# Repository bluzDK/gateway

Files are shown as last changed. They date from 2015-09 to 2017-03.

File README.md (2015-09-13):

<p align="center" >
Bluz
</p>

Bluz Gateway Hardware Files
==========
Bluz is a Development Kit (DK) that implements the Wiring language and talks to the [Particle](https://www.particle.io/) cloud through Bluetooth Low Energy. It can be accessed through a REST API and programmed from a Web IDE.

These files have been made available online through a [Creative Commons Attribution-ShareAlike 3.0](http://creativecommons.org/licenses/by-sa/3.0/) license.

You are welcome to distribute, remix, and use these files for commercial purposes. If you do so, please attribute the original design to Bluz both on the website and on the physical packaging of the product or in the instruction manual. All derivative works must be published under the same or a similar license.

All items are subject to change over time as the product is designed, so make sure you are always looking at the latest information by pulling often.

##Sections
<b>BOM</b>: Current Bill of Materials for the gateway.

<b>Datasheets</b>: Datasheets for all major parts on the board.

<b>HW Design</b>: Schematics, board layouts, and other design files.

<b>3D Files</b>: 3D Models of the PCBA and Case

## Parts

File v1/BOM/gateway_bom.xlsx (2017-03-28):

Part(s) | Package | Value | Description | Qty | Manufacturer | Mfg. Part Number | Data Sheet | Notes
U2 | SMD |  | nrf51822 module with 32K RAM | 1 | Raytac | MDBT40 | data (http://www.raytac.com/download/MDBT40/MDBT40%20spec-Version%20M.pdf)
U1 | SOT-23 |  | Linear Regulator with 3.3V output | 1 | Microchip | MCP1825S-3302E/DB | data (http://www.microchip.com/mymicrochip/filehandler.aspx?ddocname=en531698)
U3 | SMD |  | Particle P1 Module | 1 | Particle | P1 | data (https://docs.particle.io/datasheets/p1-datasheet/)
U4 | SOIC-8 |  | 2Mb SPI Flash | 1 | Microchip | SST25VF020B-80-4I-SAE | data (http://ww1.microchip.com/downloads/en/DeviceDoc/20005054C.pdf)
Q1 |  | 32.768KHz | 20ppm, 9pF, 32.768KHz crystal | 1 |  | ABS06-32.768KHZ-9-T | data (http://www.abracon.com/Resonators/ABS06.pdf)
C1-C4, C8, C10, C12, C14 | 0603 | 0.1uF | 0603 Package | 8 |  | GRM188R71C104KA01D | data (http://search.murata.co.jp/Ceramy/image/img/A01X/partnumbering_e_01.pdf)
C5, C6 | 0603 | 12pF | 0603 Package | 2 |  | CL10C120JB8NNNC | data (http://www.samsungsem.com/kr/front/downloadcms.do?fileName=S_CL10C120JB8NNNC.pdf)
C7 | 0603 | 1uF | 0603 Package | 1 |  | CL10B105KP8NNNC | data (http://www.samsungsem.com/kr/front/downloadcms.do?fileName=S_CL10B105KP8NNNC.pdf)
C9, C11, C13, C15 | 0603 | 10uF | 0603 Package | 4 |  | CL10A106MQ8NNNC | data (http://www.samsungsem.com/kr/support/product-search/mlcc/__icsFiles/afieldfile/2015/08/14/S_CL10A106MQ8NNNL.pdf)
R1-R4 | 0603 | 1K Ohm | 1k Ohm | 4 |  | CRCW06031K00FKEA | data (http://www.vishay.com/docs/20035/dcrcwe3.pdf)
L1 | SMD |  | 3.2mm x 2.7m RGB LED | 1 |  | 597-7701-207F | data (http://www.dialight.com/Assets/Brochures_And_Catalogs/Indication/597-77x1-2xx.pdf)
J1 | Thru |  | USB A Male Connector | 1 | Molex | 480371000 | data (http://www.molex.com/pdm_docs/sd/480371000_sd.pdf)

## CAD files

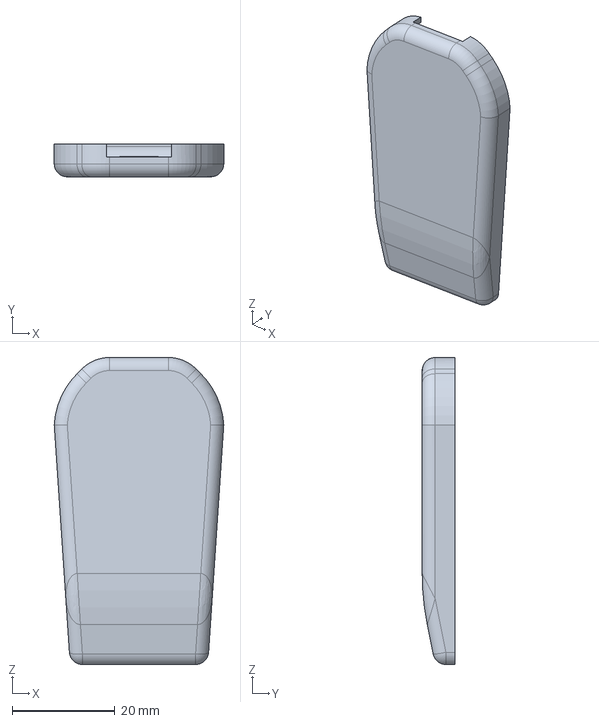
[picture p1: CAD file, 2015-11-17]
v1/3DFiles/Case/21mnb23.stp
33.0 x 6.35 x 59.7 mm

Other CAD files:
v1/3DFiles/Case/21mnb23.stl

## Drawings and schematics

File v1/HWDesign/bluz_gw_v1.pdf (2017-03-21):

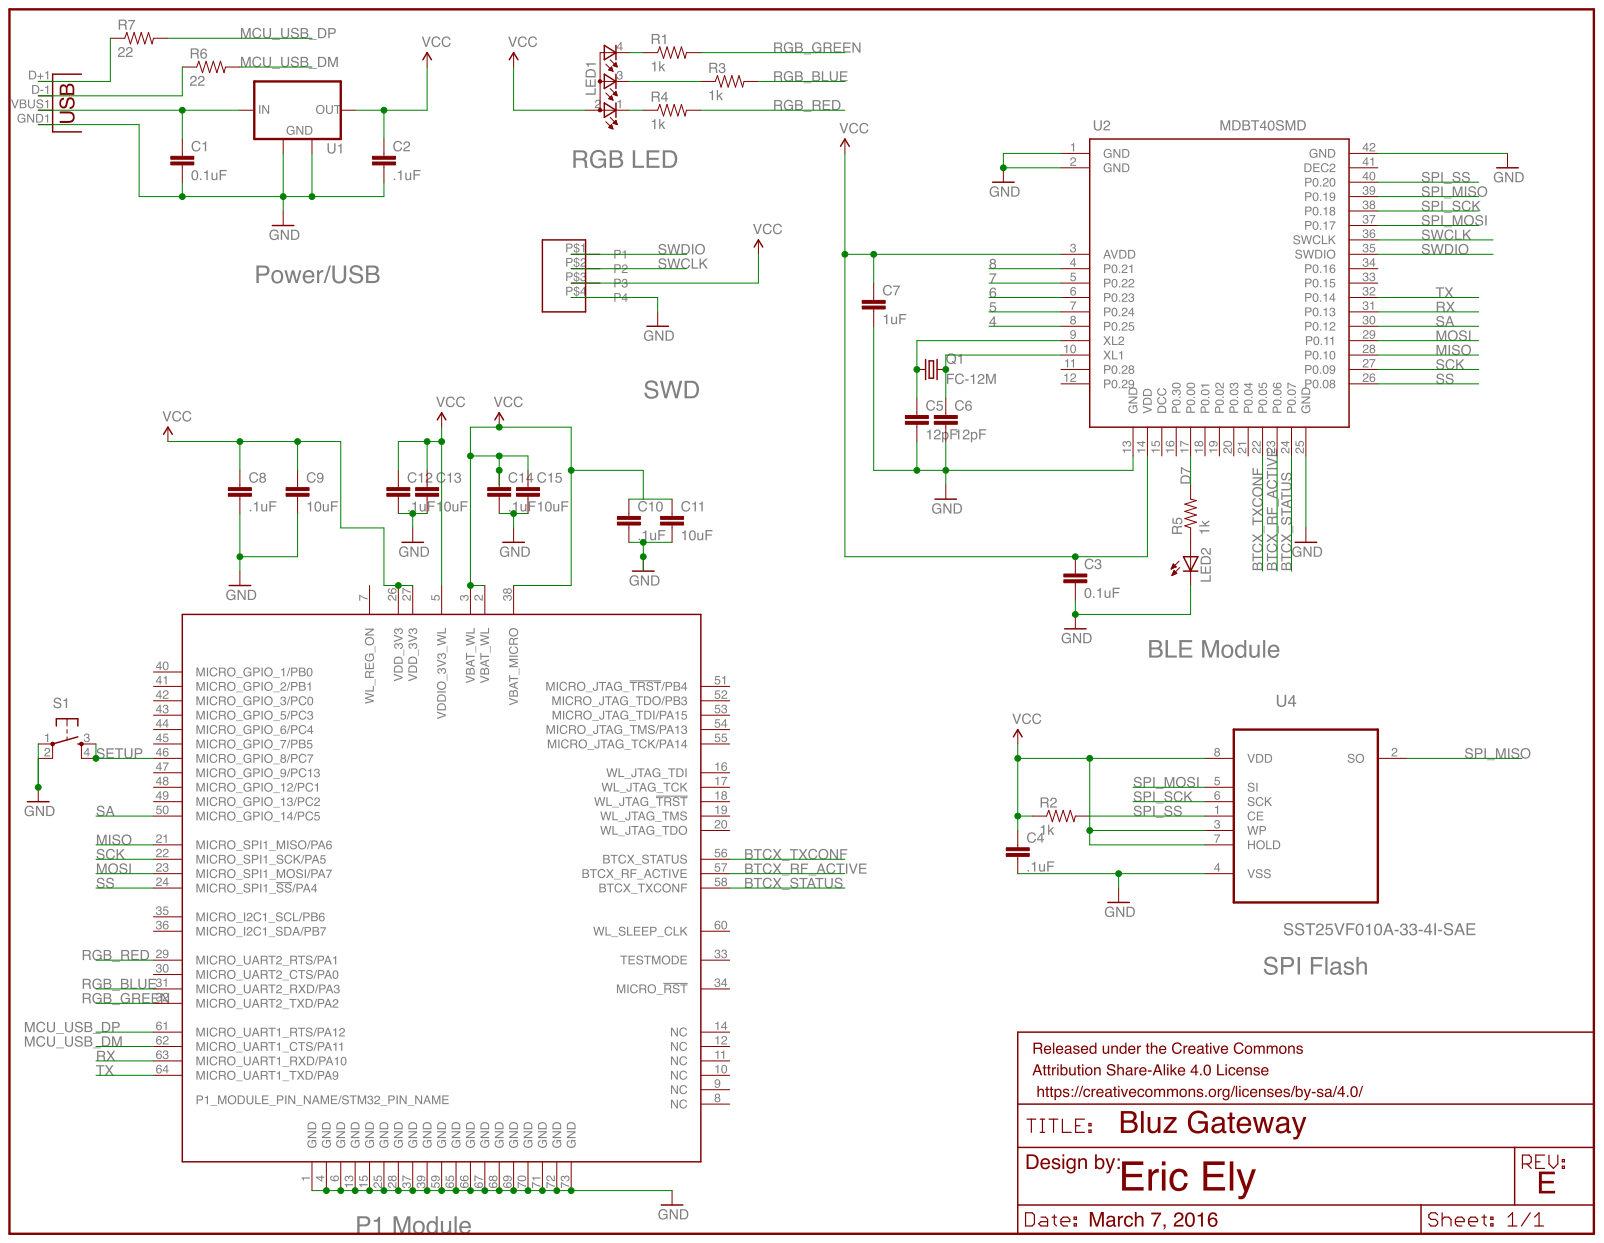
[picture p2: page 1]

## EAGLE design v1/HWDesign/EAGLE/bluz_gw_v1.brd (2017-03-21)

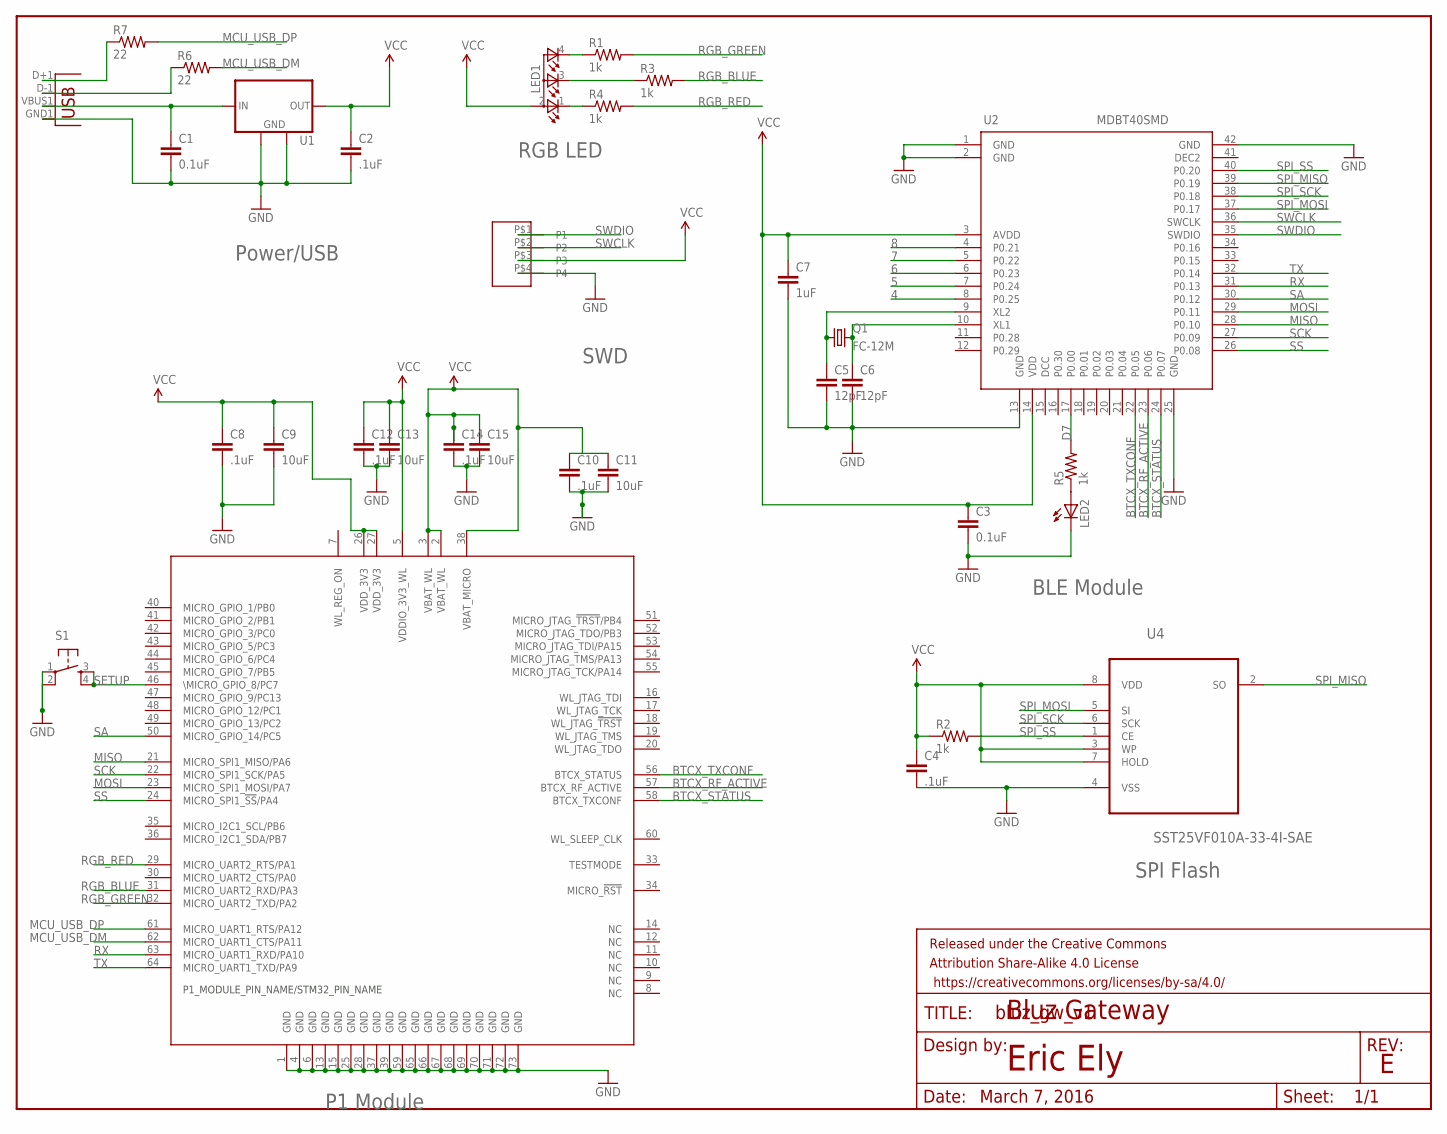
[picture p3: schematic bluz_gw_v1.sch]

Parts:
C1, C3: 0.1uF; 0603-CAP
C2, C4, C8, C10, C12, C14: .1uF; 0603-CAP
C5, C6: 12pF; 0603-CAP
C7: 1uF; 0603-CAP
C9, C11, C13, C15: 10uF; 0603-CAP
FRAME1: FRAME-LETTER; CREATIVE_COMMONS
JP2: USBA-SMD-MALE; USB-A-SMT-MALE
LED1: TOPLED-3PLCC; P-LCC-4-3
LED2: LEDCHIP-LED0603; CHIP-LED0603
Q1: FC-12M
R1, R2, R3, R4, R5: 1k; 0603-RES
R6, R7: 22; 0603-RES
S1: TAC_SWITCHSMD; TACTILE_SWITCH_SMD
U1: MCP1825S-SOT223; SOT223
U2: MDBT40SMD; MDBT40
U3: WM-N-BM-14
U4: SST25VF010A-33-4I-SAE; SOIC127P600X175-8N
U$3: POGO_CONNECTORPOGO_CONNECTOR; POGO_CONNECTER

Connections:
4: U2.8 (P0.25)
5: U2.7 (P0.24)
6: U2.6 (P0.23)
7: U2.5 (P0.22)
8: U2.4 (P0.21)
BTCX_RF_ACTIVE: U2.23 (P0.06), U3.57 (BTCX_RF_ACTIVE)
BTCX_STATUS: U2.24 (P0.07), U3.58 (BTCX_TXCONF)
BTCX_TXCONF: U2.22 (P0.05), U3.56 (BTCX_STATUS)
D7: R5.2, U2.17 (P0.00)
GND: C1.2, C2.2, C3.2, C4.2, C5.2, C6.2, C7.2, C8.2, C9.2, C10.2, C11.2, C12.2, C13.2, C14.2, C15.2, JP2.GND1 (GND), LED2.C, S1.1, S1.2, U1.2 (GND), U1.4 (GND), U2.1 (GND), U2.2 (GND), U2.13 (GND), U2.25 (GND), U2.42 (GND), U3.1 (GND), U3.4 (GND), U3.6 (GND), U3.13 (GND), U3.15 (GND), U3.25 (GND), U3.28 (GND), U3.37 (GND), U3.39 (GND), U3.59 (GND), U3.65 (GND), U3.66 (GND), U3.67 (GND), U3.68 (GND), U3.69 (GND), U3.70 (GND), U3.71 (GND), U3.72 (GND), U3.73 (GND), U4.4 (VSS), U$3.P$4 (P4)
MCU_USB_DM: R6.2, U3.62 (MICRO_UART1_CTS/PA11)
MCU_USB_DP: R7.2, U3.61 (MICRO_UART1_RTS/PA12)
MISO: U2.28 (P0.10), U3.21 (MICRO_SPI1_MISO/PA6)
MOSI: U2.29 (P0.11), U3.23 (MICRO_SPI1_MOSI/PA7)
unnamed: C1.1, JP2.VBUS1 (VBUS), U1.1 (IN)
unnamed: LED1.4 (CGREEN), R1.1
unnamed: LED1.3 (CBLUE), R3.1
unnamed: LED1.1 (CRED), R4.1
unnamed: JP2.D-1 (D-), R6.1
unnamed: JP2.D+1 (D+), R7.1
unnamed: C5.1, Q1.1, U2.9 (XL2)
unnamed: C6.1, Q1.2, U2.10 (XL1)
unnamed: LED2.A, R5.1
RGB_BLUE: R3.2, U3.31 (MICRO_UART2_RXD/PA3)
RGB_GREEN: R1.2, U3.32 (MICRO_UART2_TXD/PA2)
RGB_RED: R4.2, U3.29 (MICRO_UART2_RTS/PA1)
RX: U2.31 (P0.13), U3.63 (MICRO_UART1_RXD/PA10)
SA: U2.30 (P0.12), U3.50 (MICRO_GPIO_14/PC5)
SCK: U2.27 (P0.09), U3.22 (MICRO_SPI1_SCK/PA5)
SETUP: S1.3, S1.4, U3.46 (\MICRO_GPIO_8/PC7)
SPI_MISO: U2.39 (P0.19), U4.2 (SO)
SPI_MOSI: U2.37 (P0.17), U4.5 (SI)
SPI_SCK: U2.38 (P0.18), U4.6 (SCK)
SPI_SS: R2.2, U2.40 (P0.20), U4.1 (CE)
SS: U2.26 (P0.08), U3.24 (MICRO_SPI1_!SS!/PA4)
SWCLK: U2.36 (SWCLK), U$3.P$2 (P2)
SWDIO: U2.35 (SWDIO), U$3.P$1 (P1)
TX: U2.32 (P0.14), U3.64 (MICRO_UART1_TXD/PA9)
VCC: C2.1, C3.1, C4.1, C7.1, C8.1, C9.1, C10.1, C11.1, C12.1, C13.1, C14.1, C15.1, LED1.2 (A2), R2.1, U1.3 (OUT), U2.3 (AVDD), U2.14 (VDD), U3.2 (VBAT_WL), U3.3 (VBAT_WL), U3.5 (VDDIO_3V3_WL), U3.26 (VDD_3V3), U3.27 (VDD_3V3), U3.38 (VBAT_MICRO), U4.3 (WP), U4.7 (HOLD), U4.8 (VDD), U$3.P$3 (P3)

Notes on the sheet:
P1 Module
Power/USB
BLE Module
SWD
Eric Ely
Bluz Gateway
March 7, 2016
SPI Flash
RGB LED

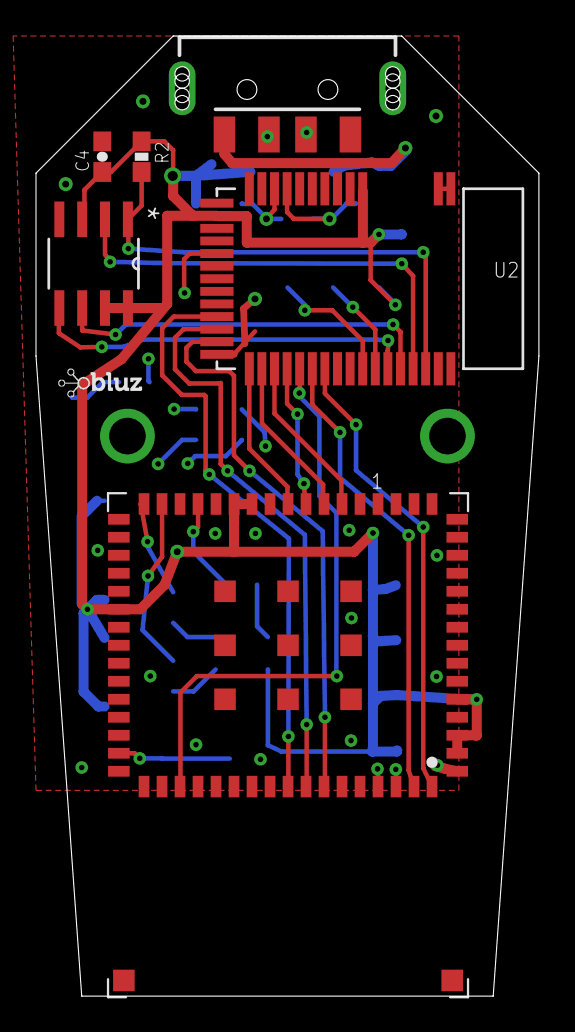
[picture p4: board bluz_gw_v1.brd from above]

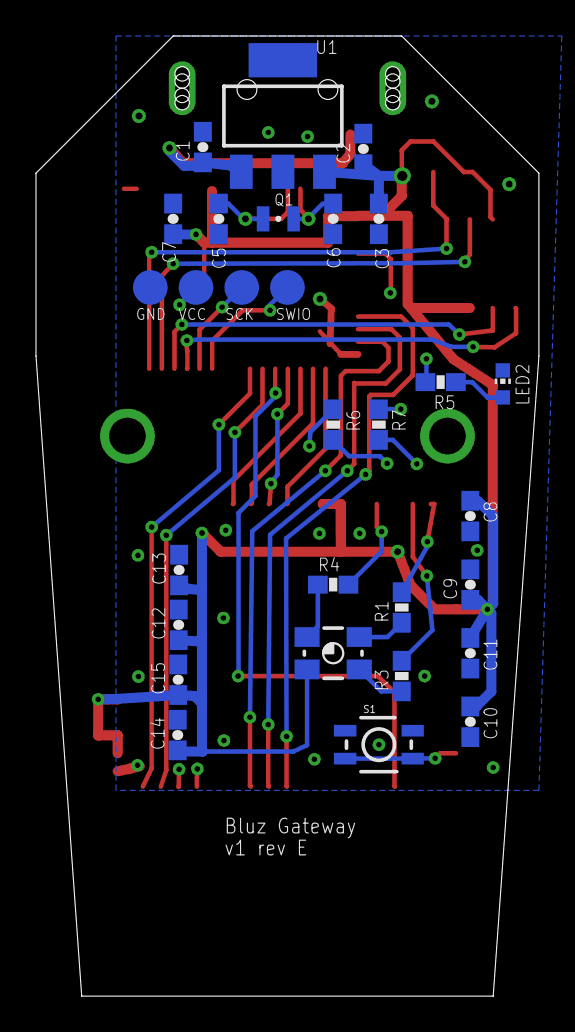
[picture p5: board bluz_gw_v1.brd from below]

Board: 2 copper layers, 27.9 x 53.3 mm, 34 parts (26 on the bottom side), 34 nets.

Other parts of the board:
U$2: BLUZE_LOGO_LOW_RES

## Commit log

2015-11-17 new design files
    [21mnb23.stl, 21mnb23.stp, bluz_gw_v1.brd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]
2017-03-21 updated hw design files
    [bluz_gw_v1.brd, bluz_gw_v1.sch]
2017-03-28 correct BOM
    [gateway_bom.xlsx]

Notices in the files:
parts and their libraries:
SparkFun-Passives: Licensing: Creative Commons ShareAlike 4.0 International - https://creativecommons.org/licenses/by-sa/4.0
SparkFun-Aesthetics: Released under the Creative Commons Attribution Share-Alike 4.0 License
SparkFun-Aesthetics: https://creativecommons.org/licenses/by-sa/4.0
